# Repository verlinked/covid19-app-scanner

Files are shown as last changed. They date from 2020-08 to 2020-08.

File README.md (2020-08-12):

# The COVID-19 App Scanner Project

Software and hardware hacks for building smart devices scanning for Bluetooth
(BLE) signals of nearby smartphones running e.g. the Corona-Warn-App.

## Idea

Imagine a device that helps to identify people having the Corona-Warn-App
installed on their smartphones. This could be useful in various scenarios.

For example, a party location where only people get access having the app on
their phones. Or giving people a free drink when they have the app
active and running. Or get something from a candy machine when you place your
smartphone in front of it.

## How it works

An COVID-19 app scanner device scans for Bluetooth Low Energy (BLE) signals
from a "Contact Detection Service" running on a smartphone (iOS or Android).
The contact detection service is a BLE service used by the Corona-Warn-App.

By checking the signal strength (RSSI) the scanner device can decide how close
the smartphone is and update the detection result.

Bringing the smartphone close to the detection device narrows the signals down
to one device if several are in the room. Once the device is close enough the
scanner device may light up green to indicate that this device has the
Corona-Warn-App installed.

## Example

The first example of a COVID-19 App Scanner device is the
[Green Tower](examples/green_tower) made by
[verlinked](https://www.verlinked.com).

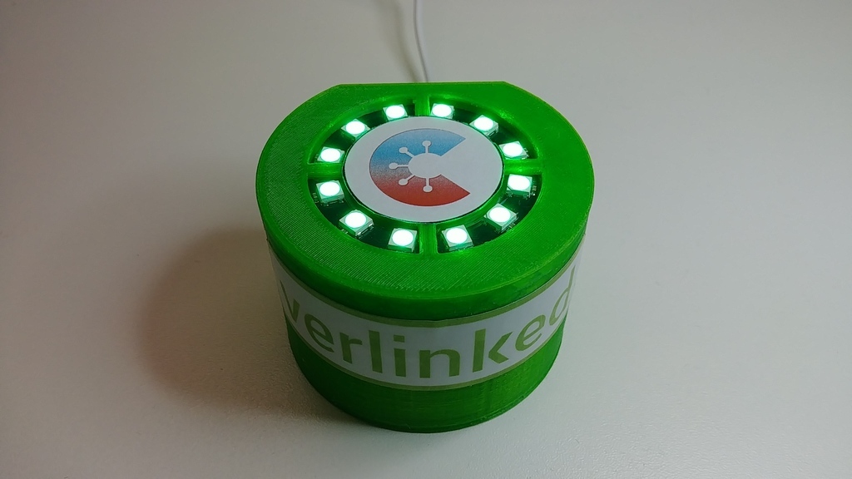
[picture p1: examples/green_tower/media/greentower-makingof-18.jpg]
The 'Green Tower' by verlinked


## How to build one

We do not have ready to use kits (yet) to make it easy for everyone to build
a smart scanning device. You need knowledge about hardware, embedded software,
3D design and 3D printing to create your own device.

But for all the hackers out there it should not be hard to create one from the
examples in this repository.

### Hardware

The scanner device requires a BLE hardware. We are using the widely used ESP32
chip for this purpose. An Internet search reveals many different variants of
these Arduino compatible chips. We are using the Arduino IDE for our code
examples.

Additionally some LED or an LED strip is required to indicate the scan
result. Some sort of display would also be possible. There are endless
possiblities.

### Software

This repository contains source code examples for building a scan device. The
code is open source an can be used for free. Just acknolwedge the copyright
notice when publishing the code somewhere else.

### Cases

The examples may also include files for 3D printable parts. Those can also
be used for your own projects.

## Background

It is everyones responsibility to keep distance from each other in times of the
COVID-19 pandemic. Smartphones help us to track contacts with other people and
to be informed about contacts we may have had with persons infected with
COVID-19.

In Germany the "Corona-Warn-App" was published to make it easy and secure for
such a tracking system. Read more about the app and get it from
[here](https://www.corona-warn-app.de).

The app uses Bluetooth Low Eneger (BLE) signals to indicate to other smartphones
that it is nearby. By exchanging encrypted IDs in an anonymous way, the phones
track when they have met other phones.

A device that checks whether a smartphone is equipped with the app has to check
for the BLE signals. If a smartphone is sending certain kinds of BLE packets
the scanning device can assume that the Corona-Warn-App is installed on that
device.

The details about the BLE communication is documented in the
[Contact Tracing - Bluetooth Specification](https://blog.google/documents/58/Contact_Tracing_-_Bluetooth_Specification_v1.1_RYGZbKW.pdf)
and the
[Contact Tracing - Cryptography Specification](https://blog.google/documents/56/Contact_Tracing_-_Cryptography_Specification.pdf).

## About

This project was initiated by the [verlinked GmbH](https://www.verlinked.com) -
a software company located in Paderborn, Germany.

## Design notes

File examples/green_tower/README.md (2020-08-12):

# The verlinked Green Tower

This is a smart COVID-19 app scanner device which checks for a nearby
smartphone having the Corona-Warn-App installed.

The 'Green Tower' by verlinked

## Hardware

The project uses a ESP32 and a Neo Pixel LED circle.

## Source Code

The sources are formatted for the Arduino IDE in `green_tower_esp32`.

## Case

The case was printed with an "Ender 3" 3D printer. As construction software
the open source tool FreeCAD was used. The corresponding files are in `CAD`.

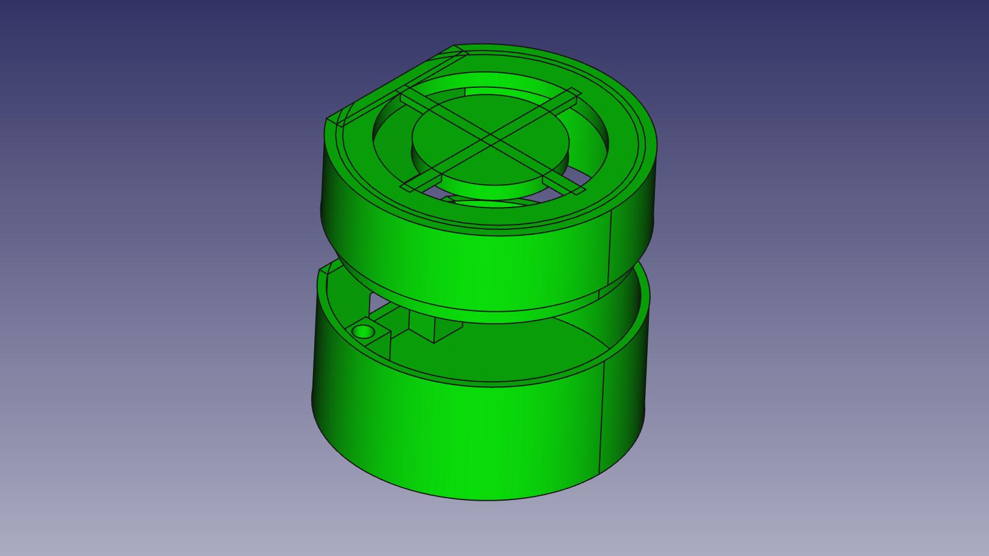
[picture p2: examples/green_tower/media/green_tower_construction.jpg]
The 'Green Tower' 3D design


## In Action

This shows the scanning in a simplified version.

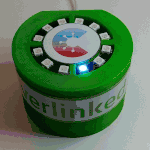
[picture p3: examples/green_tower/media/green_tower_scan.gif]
The 'Green Tower' scan in action


## Making Of

Some pictures of the [making of the 'Green Tower'](makingof).

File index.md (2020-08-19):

---
title: The COVID-19 App Scanner Project
---

# The Idea

Imagine a device that helps to identify people having the Corona-Warn-App
installed on their smartphones. This could be useful in various scenarios.

For example, a party location where only people get access having the app on
their phones. Or giving people a free drink when they have the app
active and running. Or implement a counter to detect more than one smartphone
at a time.

# Example

The first example of a COVID-19 App Scanner device is the
[Green Tower](examples/green_tower) made by
[verlinked](https://www.verlinked.com).

The 'Green Tower' by verlinked

# We want you

The components needed to build a Covid-19 App Scanner are a BLE hardware, such as an ESP32 chip, some LEDs or a display and your creativity. 

We are sure, there are plenty of possibilities to build a custom case made from wood, plastic, recycled materials et cetera. 

**Show us your custom made Covid-19 App Scanner device.** 

Take some pictures of your individual App-Scanner - and maybe some of the making of - 
and show them by [creating a pull request](https://github.com/verlinked/covid19-app-scanner/pulls) or [opening an issue](https://github.com/verlinked/covid19-app-scanner/issues).

We'll add your custom made Covid-19 App Scanner to our example gallery.   

# The Project

Visit the GitHub [project page](https://github.com/verlinked/covid19-app-scanner) to learn more.

# About

This project was initiated by the [verlinked GmbH](https://www.verlinked.com) -
a software company located in Paderborn, Germany.

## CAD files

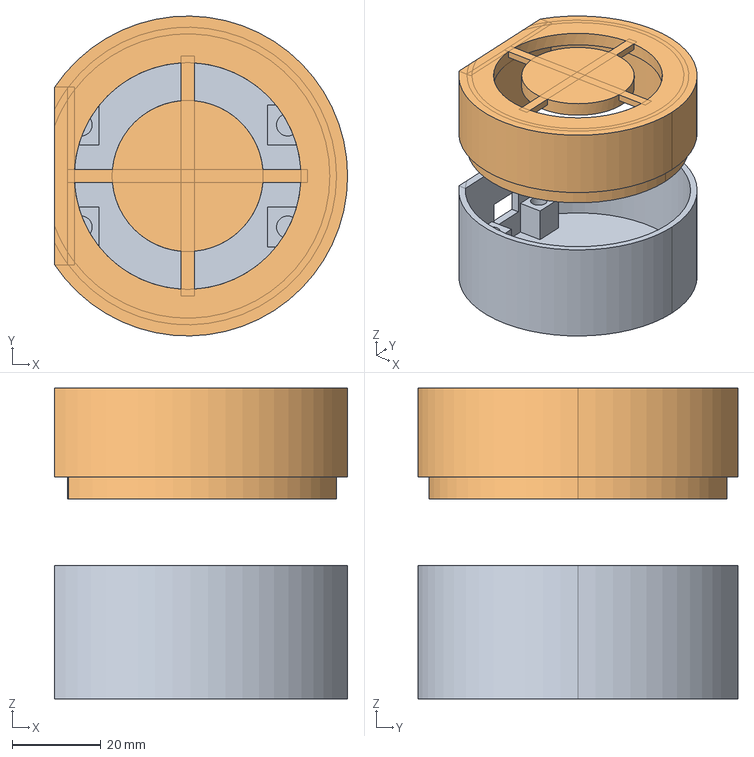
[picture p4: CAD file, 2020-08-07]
examples/green_tower/CAD/green_tower.fcstd
66.0 x 72.0 x 70.0 mm
green_tower_bottom
green_tower_top

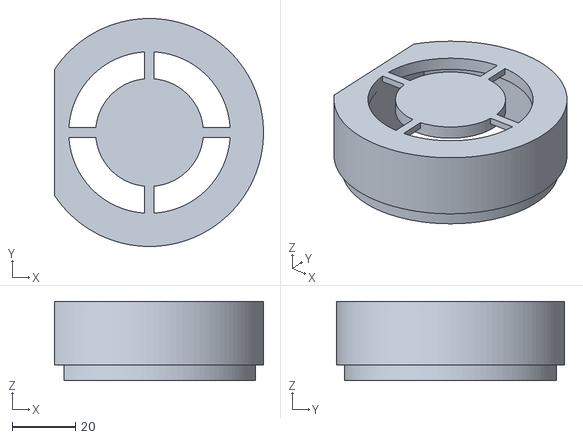
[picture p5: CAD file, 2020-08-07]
examples/green_tower/CAD/green_tower_top.stl
66.0 x 72.0 x 25.0

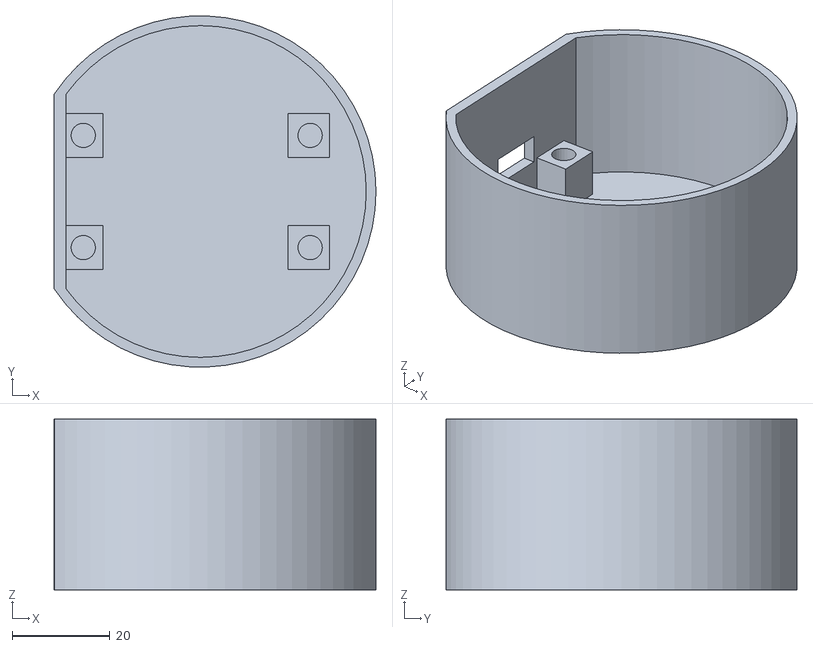
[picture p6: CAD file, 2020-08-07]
examples/green_tower/CAD/green_tower_bottom.stl
66.0 x 71.9 x 35.0

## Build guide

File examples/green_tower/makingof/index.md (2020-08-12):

---
title: C19AS - Making of: Green Tower Project
---

## Making of: The 'Green Tower'

On this page, we are showing the complete process of making the 'Green Tower' COVID-19 App Scanner device as an example.

|:-:|:-:|
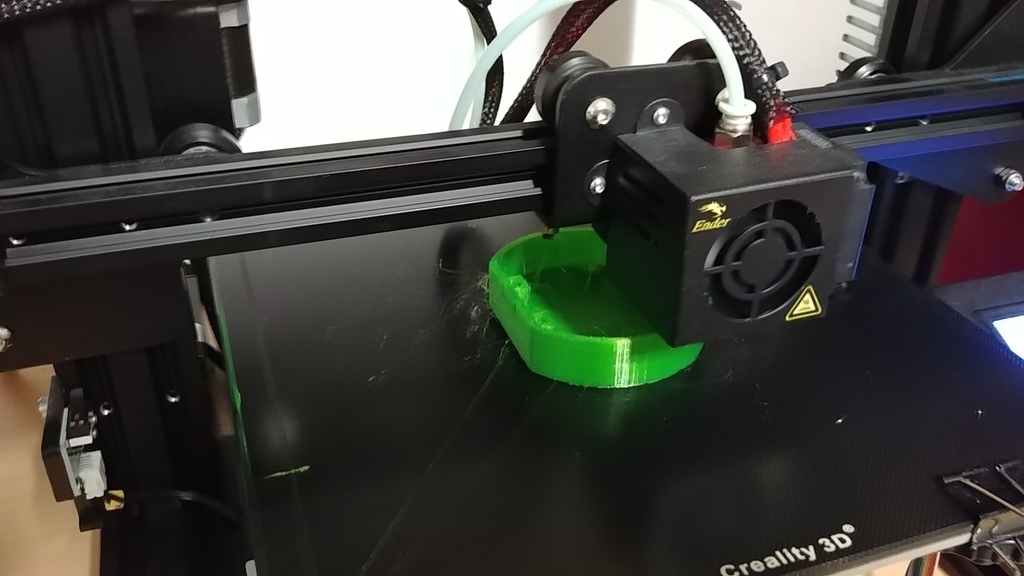
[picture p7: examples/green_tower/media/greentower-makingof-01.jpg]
3D Printer on duty
|  | Printing the shell for the device. The 3D printer is printing the bottom part of the 'Green Tower'. |
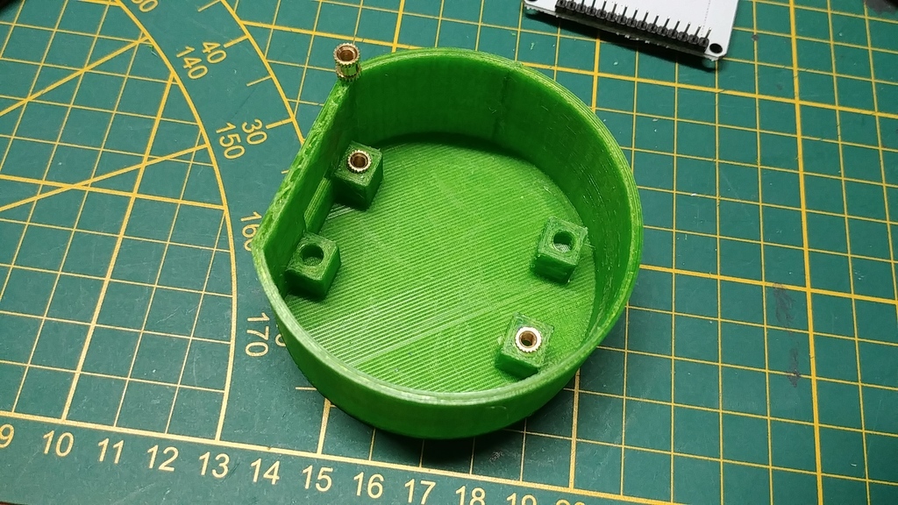
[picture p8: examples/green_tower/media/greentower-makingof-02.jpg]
Insert threaded inserts
| Put threaded inserts into the openings. This allows the screws to be loosened and tightened as often as required. |  |
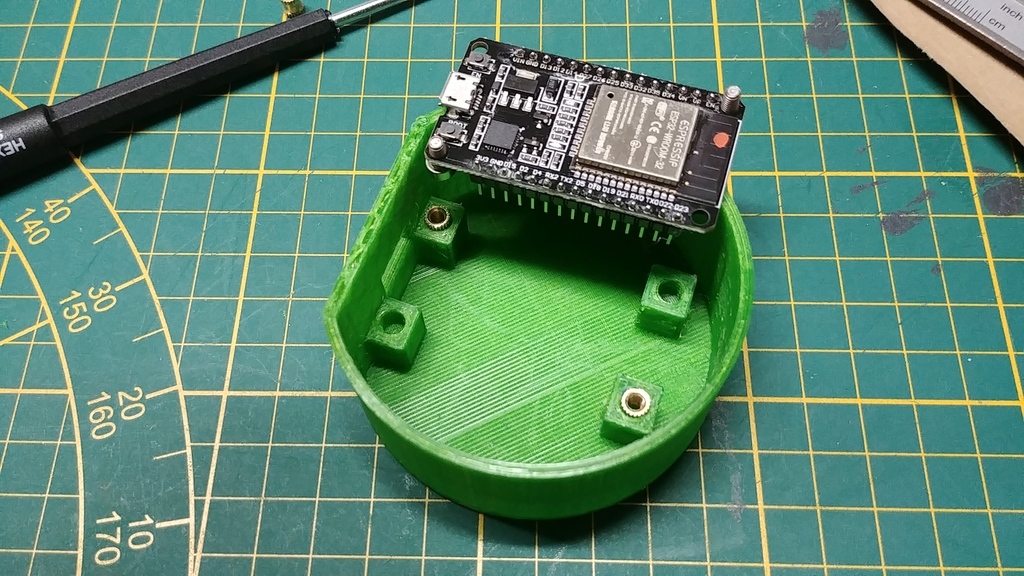
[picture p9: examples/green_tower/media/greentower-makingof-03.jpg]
The ESP32
|  | This is the ESP32. The Covid-19 App Scanner is installed. |
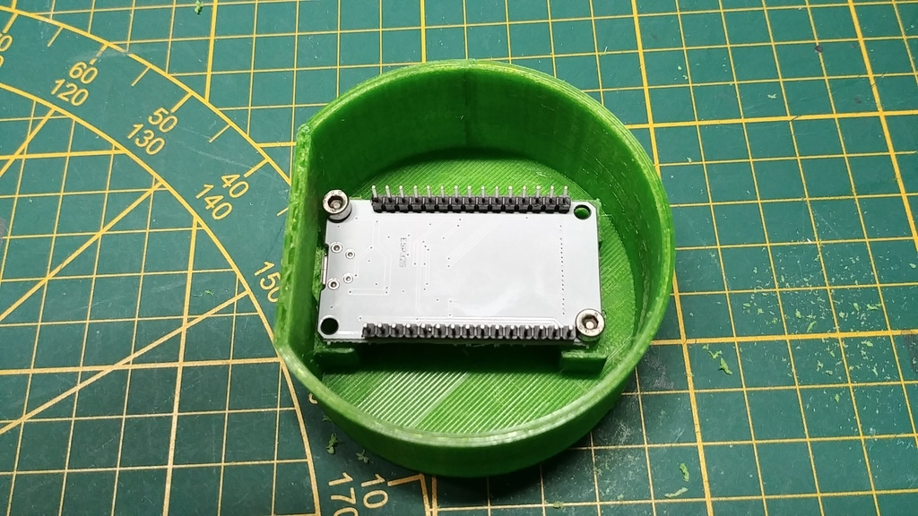
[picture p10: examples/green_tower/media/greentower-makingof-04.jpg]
Install the ESP32
| Screw the ESP32 into the case. The screws fit perfectly into the printed openings. |  |
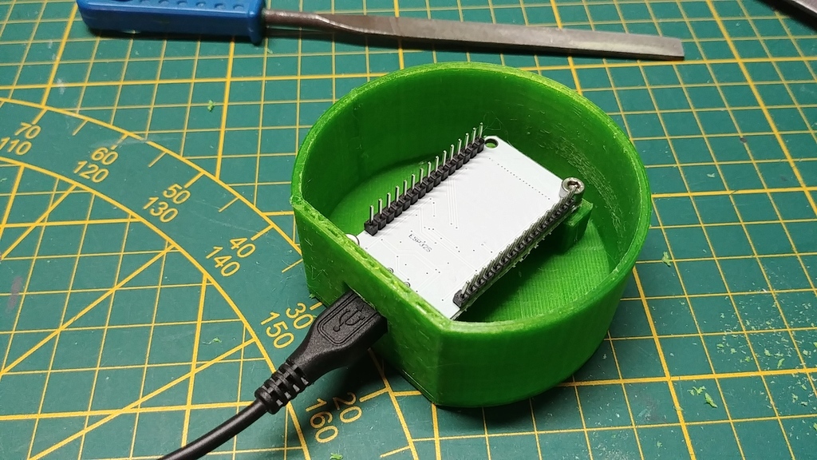
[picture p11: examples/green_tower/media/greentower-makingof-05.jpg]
Check the power cable
|  | Feed the power cable through the opening provided and connect it to the ESP32. |
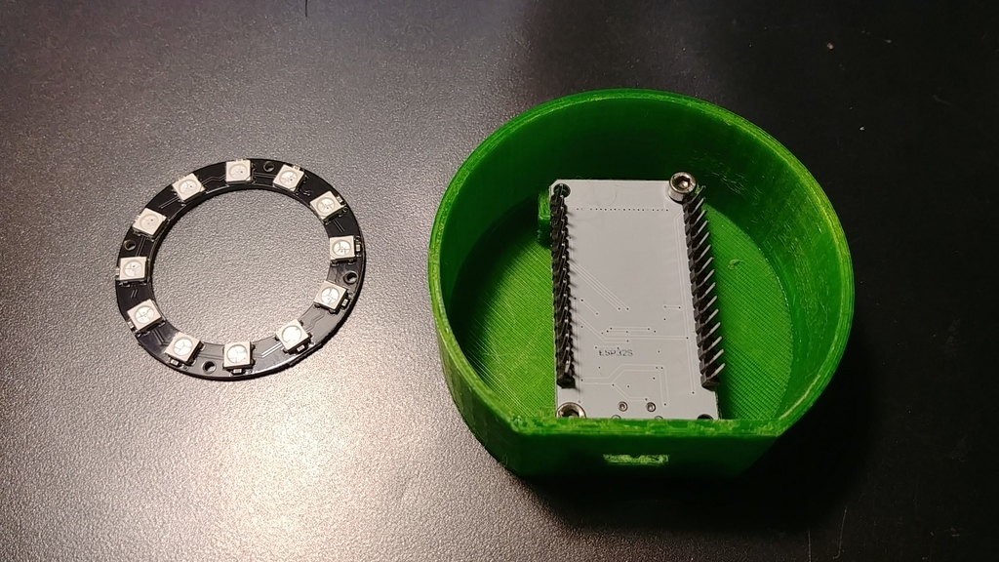
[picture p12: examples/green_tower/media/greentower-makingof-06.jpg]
Bottom done
| That's all for the bottom part of the 'Green Tower'. Next prepare the LED-Strip for the top part of the case. |  |
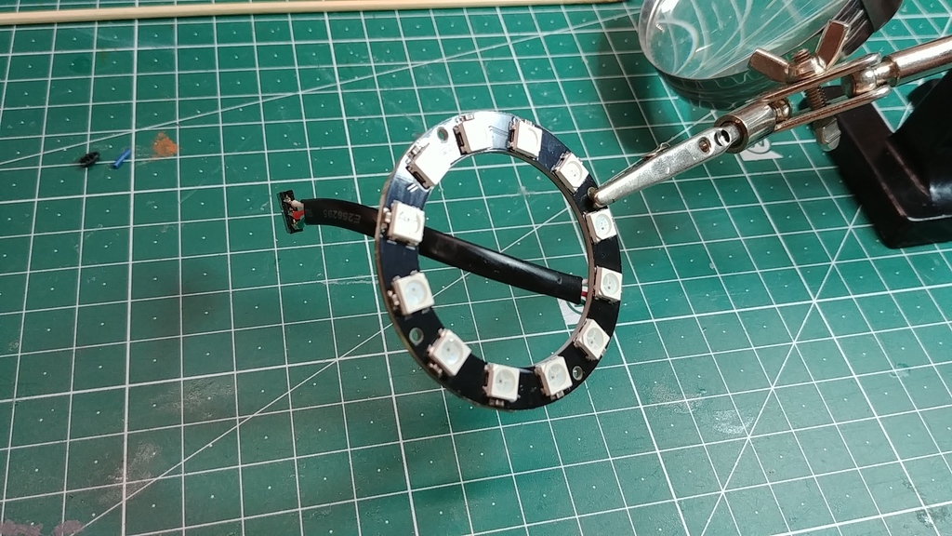
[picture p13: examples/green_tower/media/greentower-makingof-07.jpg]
Solder a cable to the LEDs
|  | Solder a short cable to the LED-strip. |
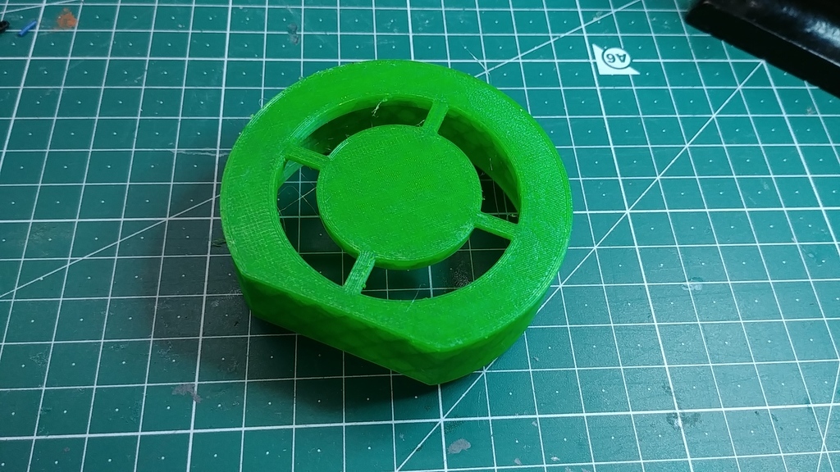
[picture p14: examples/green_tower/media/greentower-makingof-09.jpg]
Top of the case
| This is the top of the 'Green Tower' containing an opening for the LED-strip. |  |
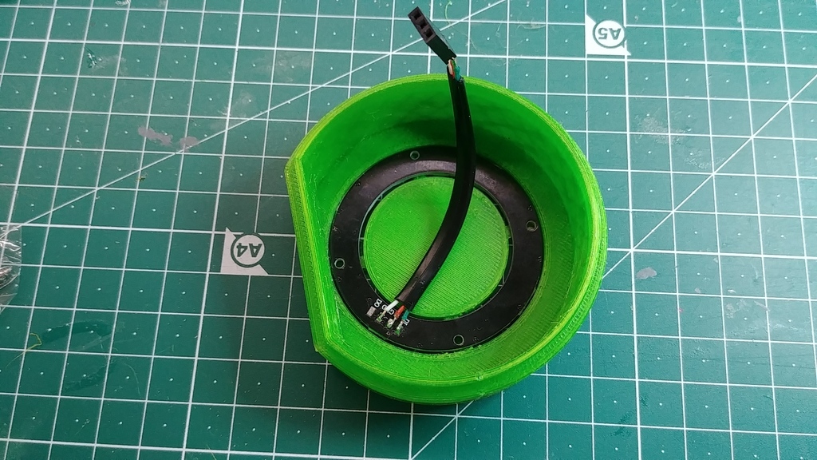
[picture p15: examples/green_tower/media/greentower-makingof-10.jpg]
Install the LED-strip
|  | The LED-Strip fits perfectly into the 3D printed top. |
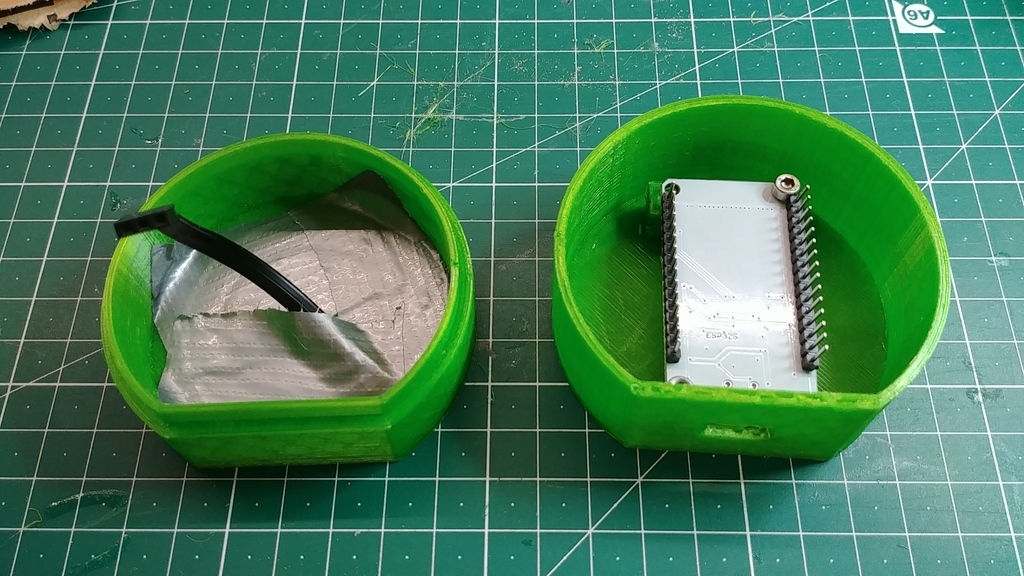
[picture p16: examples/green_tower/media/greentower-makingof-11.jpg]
Attach the LEDs
| Use duct tape to keep the LED-strip in place. |  |
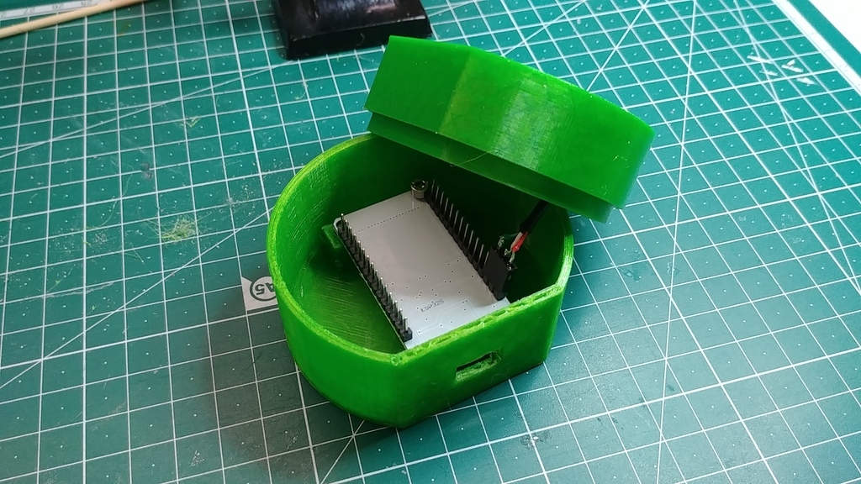
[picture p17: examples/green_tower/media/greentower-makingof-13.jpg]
Connect the ESP32 and the LEDs
|  | Plug the LED-Strip into the ESP32 and shut the case. |
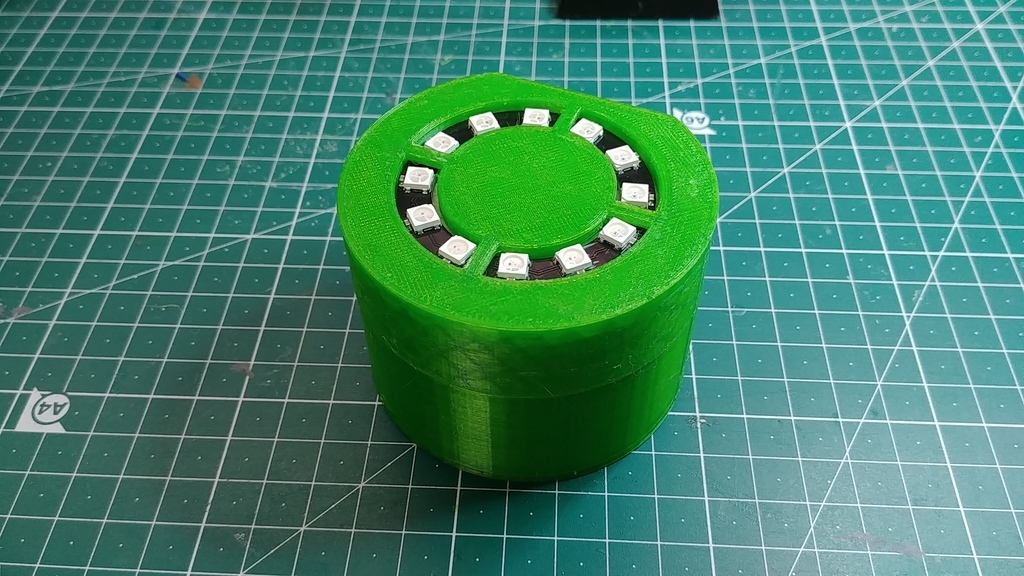
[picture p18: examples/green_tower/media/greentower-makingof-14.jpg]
Prototype finished
| Finally connected: Top and bottom parts of the tower. |  |
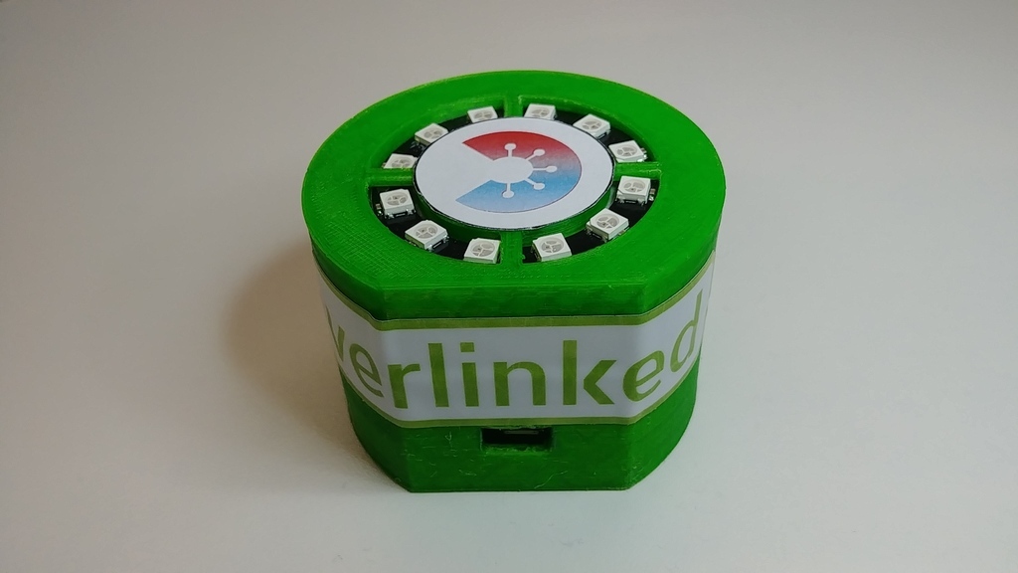
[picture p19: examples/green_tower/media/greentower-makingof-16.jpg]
Customize
|  | We customized the 'Green Tower' with the Logo of our company as well as the official logo of the Corona-Warn-App. |
| The COVID-19 App Scanner in action: All lights green: Corona-Warn-App on a device nearby found. | Corona-Warn-App found |
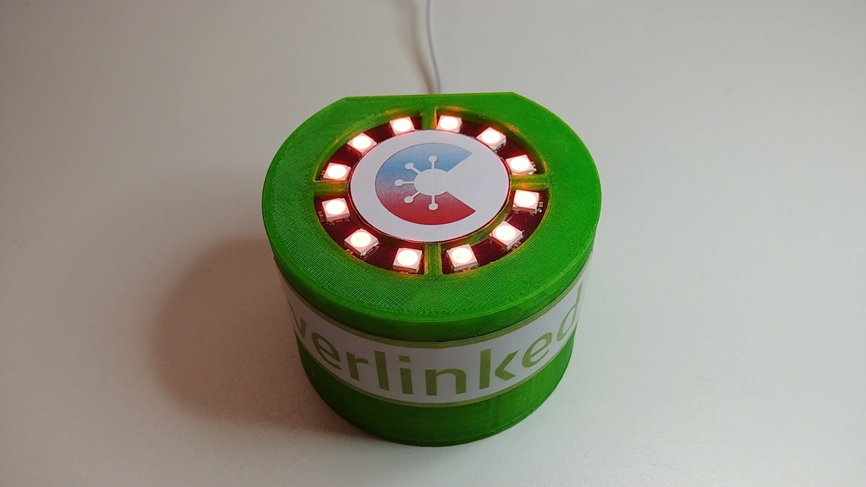
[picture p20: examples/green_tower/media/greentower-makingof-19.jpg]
No Corona-Warn-App found
|  | All lights red: No Corona-Warn-App found. |

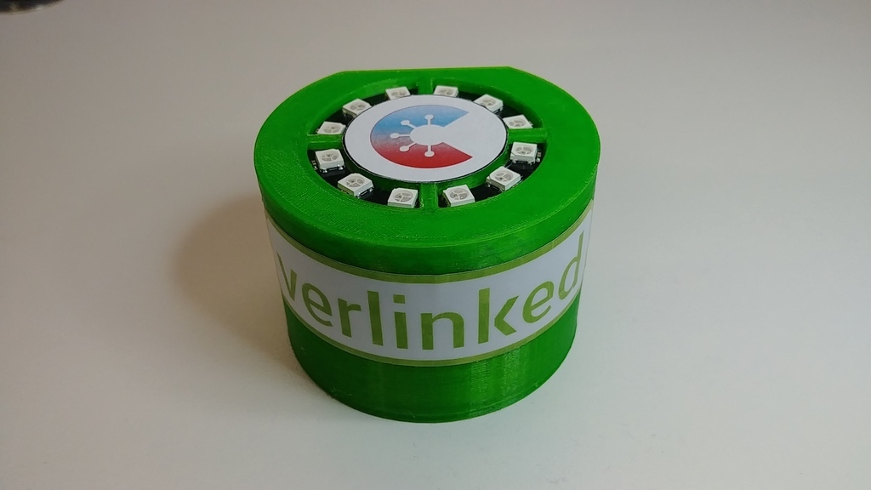
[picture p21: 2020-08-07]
examples/green_tower/media/greentower-makingof-15.jpg

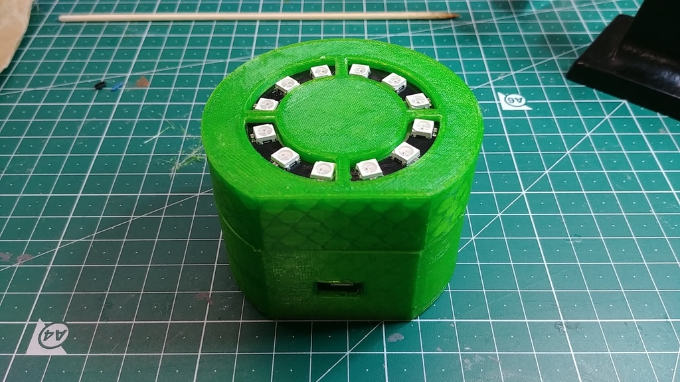
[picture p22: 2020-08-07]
examples/green_tower/media/greentower-makingof-12.jpg

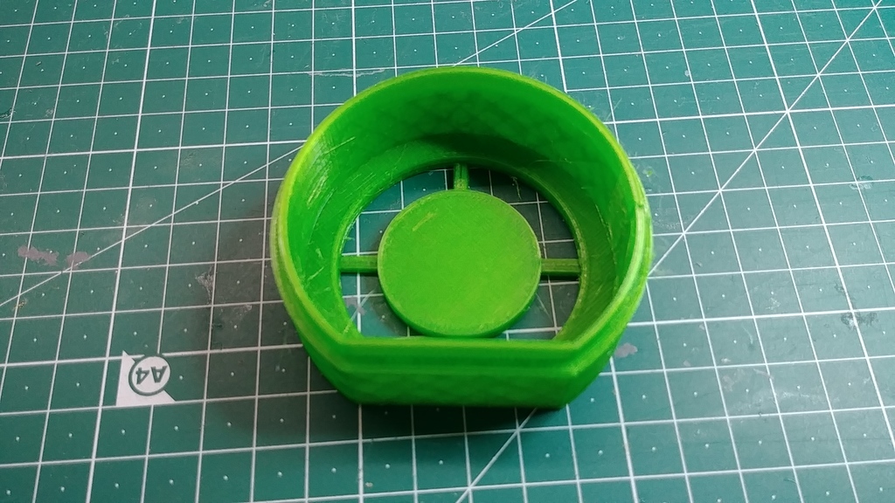
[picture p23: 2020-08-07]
examples/green_tower/media/greentower-makingof-08.jpg

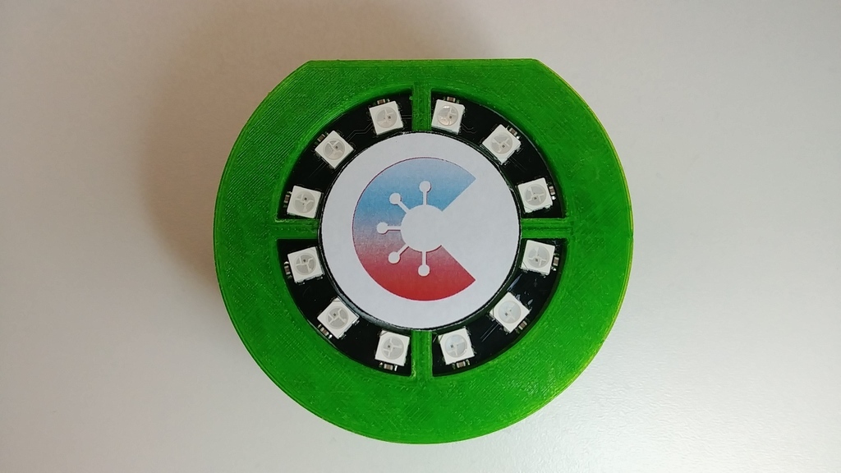
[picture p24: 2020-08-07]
examples/green_tower/media/greentower-makingof-17.jpg

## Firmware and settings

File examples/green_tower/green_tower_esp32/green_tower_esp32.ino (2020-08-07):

/*  

  Copyright (c) 2020, verlinked GmbH
  
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
  1. Redistributions of source code must retain the above copyright notice, this
     list of conditions and the following disclaimer.
  2. Redistributions in binary form must reproduce the above copyright notice,
     this list of conditions and the following disclaimer in the documentation
     and/or other materials provided with the distribution.
  
  THIS SOFTWARE IS PROVIDED BY THE COPYRIGHT HOLDERS AND CONTRIBUTORS "AS IS" AND
  ANY EXPRESS OR IMPLIED WARRANTIES, INCLUDING, BUT NOT LIMITED TO, THE IMPLIED
  WARRANTIES OF MERCHANTABILITY AND FITNESS FOR A PARTICULAR PURPOSE ARE
  DISCLAIMED. IN NO EVENT SHALL THE COPYRIGHT OWNER OR CONTRIBUTORS BE LIABLE FOR
  ANY DIRECT, INDIRECT, INCIDENTAL, SPECIAL, EXEMPLARY, OR CONSEQUENTIAL DAMAGES
  (INCLUDING, BUT NOT LIMITED TO, PROCUREMENT OF SUBSTITUTE GOODS OR SERVICES;
  LOSS OF USE, DATA, OR PROFITS; OR BUSINESS INTERRUPTION) HOWEVER CAUSED AND
  ON ANY THEORY OF LIABILITY, WHETHER IN CONTRACT, STRICT LIABILITY, OR TORT
  (INCLUDING NEGLIGENCE OR OTHERWISE) ARISING IN ANY WAY OUT OF THE USE OF THIS
  SOFTWARE, EVEN IF ADVISED OF THE POSSIBILITY OF SUCH DAMAGE.

  The green tower examples uses an ESP32 as its BLE device and a NeoPixel
  LED circle to indicate the can results.

  The LED circle with rotate while scanning, light green when a nearby
  smartphone with the Corona-Warn-App was detected or light red after
  some timeout scanning without a result.

  Depending on the sensivity of your EPS32 variant you need to adjust
  the APP_DETECTION_RSSI_THRESHOLD which controls how close a smartphone
  has to come on order to be detected. Having this value too low will
  give you detection results from more than one smartphone nearby. This
  may not be want you want.

  You may need to change the LED_CIRCLE_PIN to match your hardware setup.

  Have fun and stay healthy!
*/

#include <BLEDevice.h>
#include <BLEUtils.h>
#include <BLEScan.h>
#include <BLEAdvertisedDevice.h>

#include <NeoPixelBrightnessBus.h>

#define APP_DETECTION_RSSI_THRESHOLD -70

#define LED_CIRCLE_PIN 13
#define LED_CIRCLE_LEN 12

#define COVID_SERVICE_UUID 0xFD6F

BLEUUID covidBLEUUID = BLEUUID((uint16_t)COVID_SERVICE_UUID);
BLEScan* covidBLEScan;

uint8_t scanTime = 1; // in seconds
bool scanning = false;
uint8_t scanTimeoutCounter = 0;

bool covidAppNearby = false;
bool covidAppNotFound = false;
uint8_t timeoutCounter = 0;

NeoPixelBrightnessBus<NeoGrbFeature, Neo800KbpsMethod> circle(LED_CIRCLE_LEN, LED_CIRCLE_PIN);

/**
 * Callback when a device was found and advertised.
 */
class BLEDeviceCallbacks: public BLEAdvertisedDeviceCallbacks {
  void onResult(BLEAdvertisedDevice advertisedDevice) {
    bool hasCovidApp = advertisedDevice.isAdvertisingService(covidBLEUUID);
    int rssi = advertisedDevice.getRSSI();
    if (hasCovidApp) {
      if (rssi > APP_DETECTION_RSSI_THRESHOLD) {
        covidAppNearby = true;
      }
    }
  }
};

/**
 * Callback invoked when scanning has completed.
 */
static void scanCompleteCallback(BLEScanResults scanResults) {
  scanning = false;
} 


/**
 * Setup the hardware.
 */
void setup() {
  circle.Begin();
  circle.SetBrightness(200);
  circle.Show();

  BLEDevice::init("");
  covidBLEScan = BLEDevice::getScan(); //create new scan
  covidBLEScan->setAdvertisedDeviceCallbacks(new BLEDeviceCallbacks(), false);
  covidBLEScan->setActiveScan(true); //active scan uses more power, but get results faster
  covidBLEScan->setInterval(100);
  covidBLEScan->setWindow(99);  // less or equal setInterval value
}

uint8_t pos = 0;
void updateCircle() {
  // Turn off
  circle.ClearTo(RgbColor(0,0,0));

  if (covidAppNearby) {
    // All green
    circle.ClearTo(RgbColor(0,150,0));
  } else if (covidAppNotFound) {
    circle.ClearTo(RgbColor(150,0,0));
  } else {
    // Update scanning circle
    pos = pos + 1;
    if (pos > 11) {
      pos = 0;
    }
    circle.SetPixelColor(pos, RgbColor(0,150,200));
  }
  circle.Show();
}

void loop() {
  if (covidAppNearby) {
    scanTimeoutCounter = 0;
    covidAppNotFound = false;
    
    // App found - start a timeout to display the green circle
    timeoutCounter = timeoutCounter + 1;
    if (timeoutCounter > 50) {
      covidAppNearby = false;
      timeoutCounter = 0;
    }
  } else if (covidAppNotFound) {
    scanTimeoutCounter = 0;
    covidAppNearby = false;
    
    // App not found - start a timeout to display the red circle
    timeoutCounter = timeoutCounter + 1;
    if (timeoutCounter > 20) {
      covidAppNotFound = false;
      timeoutCounter = 0;
    }
  } else if (scanning) {
    scanTimeoutCounter = scanTimeoutCounter + 1;
    if (scanTimeoutCounter > 60) {
      if (!covidAppNearby) {
        covidAppNotFound = true;
      }
    }
  } else {
    scanning = covidBLEScan->start(scanTime, scanCompleteCallback);
  }
  
  updateCircle();
  delay(83);
}

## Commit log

2020-08-07 Initial commit with code from Arduino project
2020-08-07 More structure refactorings. Add 3D files
    [green_tower.fcstd, green_tower_bottom.stl, green_tower_top.stl]
